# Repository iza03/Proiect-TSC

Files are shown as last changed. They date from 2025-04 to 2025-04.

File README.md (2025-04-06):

# DeskAssistant v1.5 – README

## Diagrama bloc
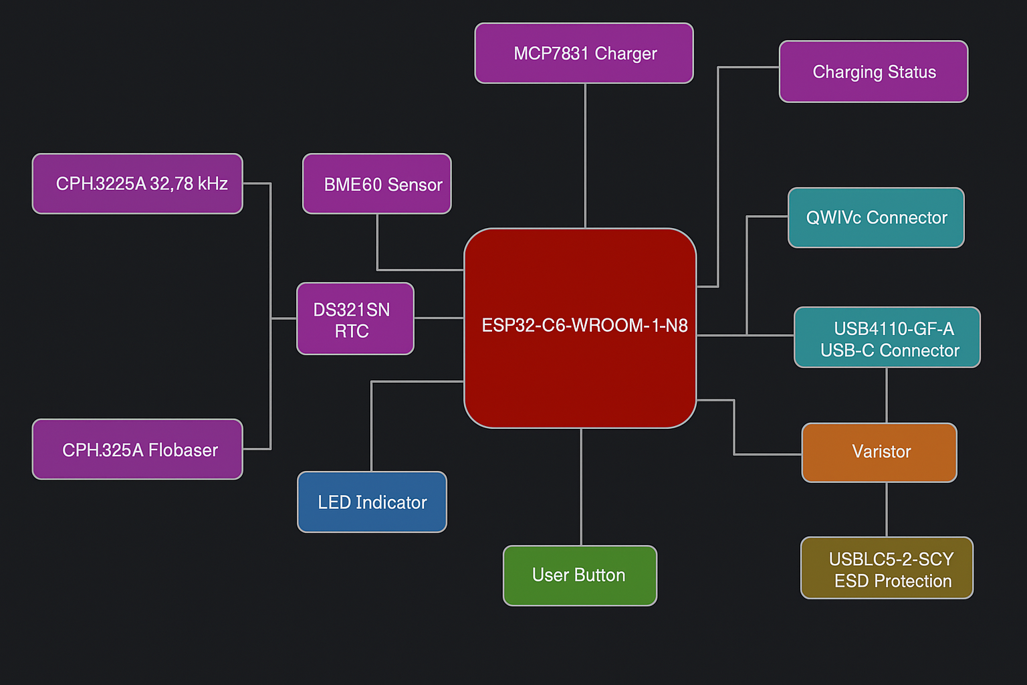
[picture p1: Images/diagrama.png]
Diagrama bloc


---

## Bill of Materials (BoM)

# Bill of Materials

| Componenta | Link |
|---|---|
| SAMACSYS_PARTS_USB4110-GF-A | [https://componentsearchengine.com/part-view/USB4110-GF-A/GCT%20(GLOBAL%20CONNECTOR%20TECHNOLOGY)](https://componentsearchengine.com/part-view/USB4110-GF-A/GCT%20(GLOBAL%20CONNECTOR%20TECHNOLOGY)) |
| SI1308EDL-T1-GE3 | [https://componentsearchengine.com/part-view/SI1308EDL-T1-GE3/Vishay](https://componentsearchengine.com/part-view/SI1308EDL-T1-GE3/Vishay) |
| SJ | [https://grabcad.com/library/solder-jumpers-1](https://grabcad.com/library/solder-jumpers-1) |
| USBLC6-2SC6Y | [https://www.snapeda.com/parts/USBLC6-2SC6Y/STMicroelectronics/view-part/?ref=eda](https://www.snapeda.com/parts/USBLC6-2SC6Y/STMicroelectronics/view-part/?ref=eda) |
| W25Q512JVEIQ | [https://www.snapeda.com/parts/W25Q512JVEIQ/Winbond+Electronics/view-part/?ref=eda](https://www.snapeda.com/parts/W25Q512JVEIQ/Winbond+Electronics/view-part/?ref=eda) |
| ESP32_WROVER_EAGLE-LTSPICE_RR0402 | [https://www.snapeda.com/parts/RC0402FR-07226RL/Yageo/view-part/](https://www.snapeda.com/parts/RC0402FR-07226RL/Yageo/view-part/) |
| ESP32C6_VARISTORCN1812 | [https://www.mouser.co.uk/ProductDetail/EPCOS-TDK/B72520T0350K062?qs=dEfas%2FXlABIszF52uu7vrg%3D%3D](https://www.mouser.co.uk/ProductDetail/EPCOS-TDK/B72520T0350K062?qs=dEfas%2FXlABIszF52uu7vrg%3D%3D) |
| FH34SRJ-24S-0.5SH_99_ | [https://componentsearchengine.com/part-view/XC6220A331MR-G/Torex](https://componentsearchengine.com/part-view/XC6220A331MR-G/Torex) |
| MAX17048G+T10 | [https://www.snapeda.com/parts/MAX17048G+T10/Analog+Devices/view-part/?ref=eda](https://www.snapeda.com/parts/MAX17048G+T10/Analog+Devices/view-part/?ref=eda) |
| MBR0530 | [https://ro.mouser.com/ProductDetail/KYOCERA-AVX/SD0805S020S1R0?qs=jCA%252BPfw4LHbpkAoSnwrdjw%3D%3D](https://ro.mouser.com/ProductDetail/KYOCERA-AVX/SD0805S020S1R0?qs=jCA%252BPfw4LHbpkAoSnwrdjw%3D%3D) |
| PGB1010603MR | [https://www.snapeda.com/parts/PGB1010603MR/Littelfuse/view-part/?ref=eda](https://www.snapeda.com/parts/PGB1010603MR/Littelfuse/view-part/?ref=eda) |
| RCL_CPOL-EUCT3528 | [https://ro.mouser.com/ProductDetail/Vishay-Sprague/TR3B106K025C1300?qs=jCGqFXxTmLdffnuDkXzk1g%3D%3D](https://ro.mouser.com/ProductDetail/Vishay-Sprague/TR3B106K025C1300?qs=jCGqFXxTmLdffnuDkXzk1g%3D%3D) |
| 112A-TAAR-R03_ATTEND | [https://store.comet.bg/en/Catalogue/Product/43497/](https://store.comet.bg/en/Catalogue/Product/43497/) |
| 744043680IND_4828-WE-TPC_WRE | [https://www.digikey.sg/en/models/1638515](https://www.digikey.sg/en/models/1638515) |
| BD5229G-TR | [https://componentsearchengine.com/part-view/BD5229G-TR/ROHM%20Semiconductor](https://componentsearchengine.com/part-view/BD5229G-TR/ROHM%20Semiconductor) |
| DS3231SN | [https://www.snapeda.com/parts/DS3231SN%23/Analog+Devices/view-part/?ref=eda](https://www.snapeda.com/parts/DS3231SN%23/Analog+Devices/view-part/?ref=eda) |
| ESP32-C6-WROOM-1-N8 | [https://www.snapeda.com/parts/ESP32-C6-WROOM-1-N8/Espressif+Systems/view-part/?ref=eda](https://www.snapeda.com/parts/ESP32-C6-WROOM-1-N8/Espressif+Systems/view-part/?ref=eda) |
| MCP73831 | [https://www.digikey.com/en/models/1874108](https://www.digikey.com/en/models/1874108) |
| XC6220A331MR-G | [https://componentsearchengine.com/part-view/XC6220A331MR-G/Torex](https://componentsearchengine.com/part-view/XC6220A331MR-G/Torex) |
| QWIIC_CONNECTORJS-1MM | [https://www.snapeda.com/parts/PRT-14417/SparkFun/view-part/](https://www.snapeda.com/parts/PRT-14417/SparkFun/view-part/) |
| BUTTON_CUSYOMV1 | [https://industry.panasonic.com/global/en/downloads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](https://industry.panasonic.com/global/en/downloads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) |
| ESP32_WROVER_EAGLE-LTSPICE_CC0402 | [https://componentsearchengine.com/part-view/CC0402MRX5R5BB106/YAGEO](https://componentsearchengine.com/part-view/CC0402MRX5R5BB106/YAGEO) |
| CPH3225A | [https://www.snapeda.com/parts/CPH3225A/Seiko+Instruments/view-part/?ref=eda](https://www.snapeda.com/parts/CPH3225A/Seiko+Instruments/view-part/?ref=eda) |
| ADAFRUIT_LEDCHIP-LED0603 | [https://www.snapeda.com/parts/KP-1608SURCK/Kingbright/view-part/?ref=search&t=LED%200603](https://www.snapeda.com/parts/KP-1608SURCK/Kingbright/view-part/?ref=search&t=LED%200603) |
| ESP32_WROVER_BME680_BME680 | [https://www.snapeda.com/parts/BME680/Bosch/view-part/?welcome=home](https://www.snapeda.com/parts/BME680/Bosch/view-part/?welcome=home) |
| ESP32_WROVER_SPARKFUN-DISCRETESEMI_MOSFET_PCH-DMG2305UX-7 | [https://componentsearchengine.com/part-view/DMG2305UX-7/Diodes%20Incorporated](https://componentsearchengine.com/part-view/DMG2305UX-7/Diodes%20Incorporated) |

---

## Funcționalități hardware

### 1. Microcontroller – ESP32-C6-WROOM-1-N8
- **Wireless:** WiFi 6, BLE 5.0, Zigbee, Thread
- **Interfețe:** UART, I²C, SPI, USB, ADC, PWM
- **Rol:** Unitate centrală de control, achiziție date, comunicare cu periferice și backend.

### 2. Senzori
- **BME688**: măsoară temperatură, umiditate, presiune și compuși organici volatili (VOC)
  - **Interfață**: I²C
- **DS3231SN**: RTC (Real Time Clock)
  - **Interfață**: I²C
- **MAX17048**: fuel gauge pentru baterie
  - **Interfață**: I²C

### 3. Memorie externă
- **W25Q512JVEIQ**
  - **Tip**: NOR Flash, 512Mbit
  - **Interfață**: SPI

### 4. Managementul energiei
- **MCP73831**: încărcător Li-Ion
- **MAX17048**: monitorizare baterie
- **BD5229G-TR**: LDO pentru 2.9V stabil
- **Diodă Schottky, MOSFET, varistor**: protecție la supratensiuni și polarizare inversă

### 5. Conectivitate și I/O
- **USB4110-GF-A**: conector USB-C pentru alimentare/comunicare
- **QWIIC connector**: I²C modular pentru senzori plug-and-play
- **LED status** și **buton fizic** (boot/reset sau input utilizator)

---

## Conexiuni GPIO la ESP32-C6

| Componentă | Interfață | GPIO ESP32-C6 | Funcție |
|---|---|---|---|
| BME688 / DS3231 / MAX17048 | I²C | GPIO8 (SDA), GPIO9 (SCL) | Magistrală partajată |
| W25Q512JVEIQ | SPI | GPIO4 (MOSI), GPIO5 (MISO), GPIO6 (CLK), GPIO7 (CS) | Comunicare cu flash extern |
| LED status | GPIO | GPIO3 | Indicator status / PWM |
| Buton | GPIO + Pull-up | GPIO0 | Reset / boot / input utilizator |
| MCP73831 – STAT | GPIO | GPIO10 | Monitorizare stare încărcare |
| MAX17048 – ALERT | GPIO (Interrupt) | GPIO1 | Notificare SoC critic |
| USB-C – D+ / D- | USB | GPIO18 (D+), GPIO19 (D-) | Comunicare USB nativă |

---

## Estimare consum energetic

| Componentă | Consum tipic |
|---|---|
| ESP32-C6 | ~130 mA (activ) |
| BME688 | ~3.1 µA |
| DS3231 | ~200 nA |
| MAX17048 | ~23 µA |
| MCP73831 | până la 500 mA (în încărcare) |
| LED-uri | 2–10 mA |

**Consum total în mod activ:** aprox. **150–180 mA**

### Randări PCB și design fizic

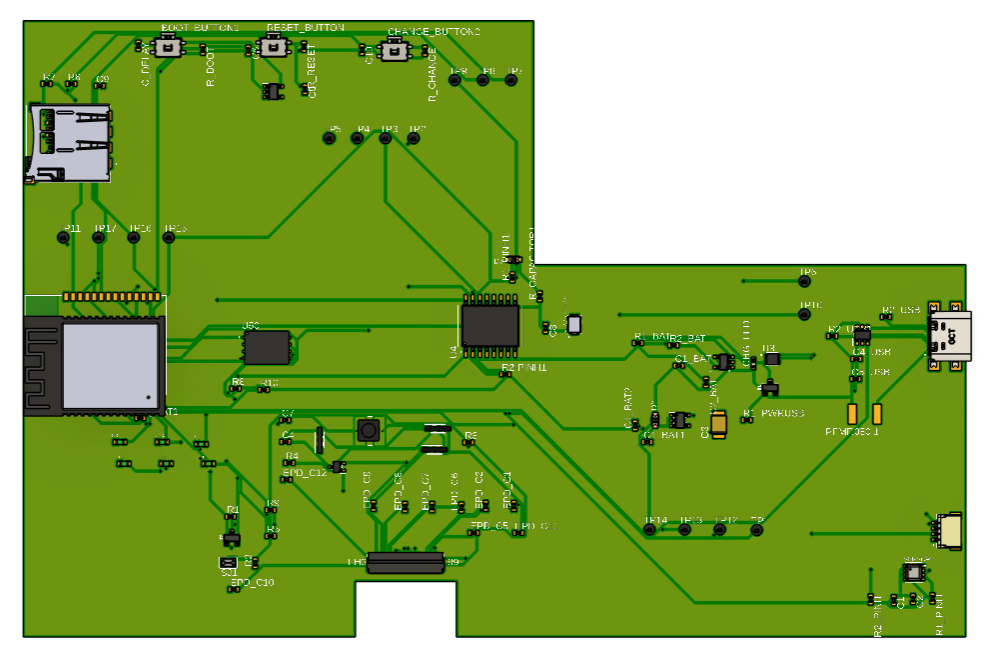
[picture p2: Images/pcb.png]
Randare PCB
  
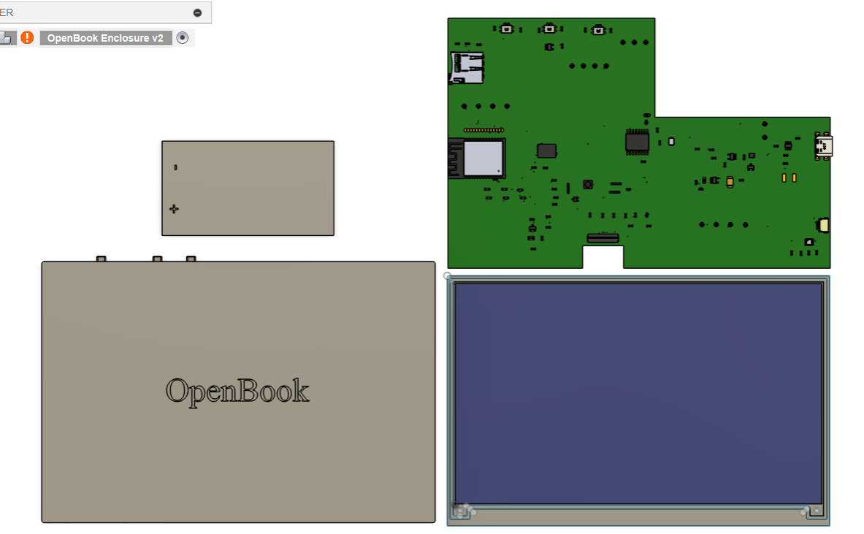
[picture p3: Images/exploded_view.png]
Vedere explodată
  
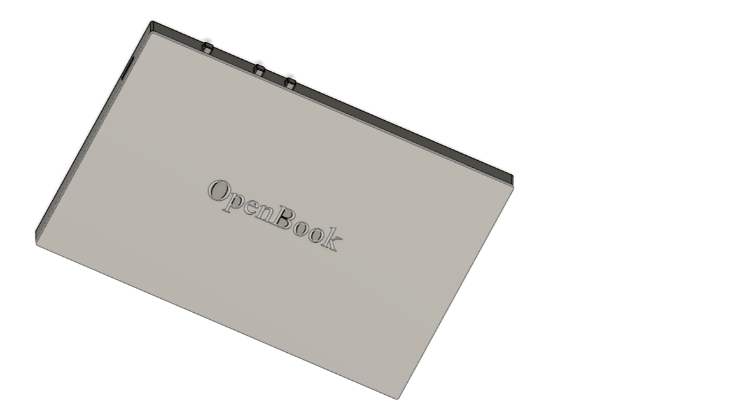
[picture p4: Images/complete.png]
Ansamblu complet


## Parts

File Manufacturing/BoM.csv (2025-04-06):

Qty | Value | Device | Package | Parts | Description | ARROW_PART_NUMBER | ARROW_PRICE-STOCK | AVAILABILITY | CENTROID_NOT_SPECIFIED | CHECK_PRICES | COPYRIGHT | DATASHEET | DESCRIPTION | DIGIKEY_DESCRIPTION | DIGIKEY_PART_NUMBER | HEIGHT | LEAD_FREE | MANUFACTURER_NAME | MANUFACTURER_PART_NUMBER | MF | MFR_NAME | MOUSER_PART_NUMBER | MOUSER_PRICE-STOCK | MOUSER_TESTING_PART_NUMBER | MOUSER_TESTING_PRICE-STOCK | MP | MPN | PACKAGE | POPULARITY | PREFIX | PRICE | PROD_ID | PURCHASE-URL | ROHS | SNAPEDA_LINK | SPICEMODEL | SPICEPREFIX | TEMPERATURE_RANGE_HIGH | TEMPERATURE_RANGE_LOW | TP_SIGNAL_NAME | VALUE
1 |  | ADAFRUIT_LEDCHIP-LED0603 | ADAFRUIT_CHIP-LED0603 | CHG_LED | LED
1 |  | SJ | SJ | SJ1 | SMD solder JUMPER |  |  |  |  |  |  |  |  |  |  |  |  |  |  |  |  |  |  |  |  |  |  |  | 3
1 | 0.1uF/50V | EAGLE-LTSPICE_CC0402 | EAGLE-LTSPICE_C0402 | EPD_C5 | CAPACITOR, European symbol |  |  |  |  |  |  |  |  |  |  |  |  |  |  |  |  |  |  |  |  |  |  |  |  |  |  |  |  |  |  | NONE | C
1 | 0.47 | ESP32_WROVER_EAGLE-LTSPICE_RR0402 | ESP32_WROVER_EAGLE-LTSPICE_R0402 | R3 | RESISTOR, European symbol |  |  |  |  |  |  |  |  |  |  |  |  |  |  |  |  |  |  |  |  |  |  |  |  |  |  |  |  |  |  | NONE | R
1 | 100k | ESP32_WROVER_EAGLE-LTSPICE_RR0402 | ESP32_WROVER_EAGLE-LTSPICE_R0402 | R1_PWRUSB | RESISTOR, European symbol |  |  |  |  |  |  |  |  |  |  |  |  |  |  |  |  |  |  |  |  |  |  |  |  |  |  |  |  |  |  | NONE | R
7 | 100nF | EAGLE-LTSPICE_CC0402 | EAGLE-LTSPICE_C0402 | C4_USB, C5_USB, C6, C8, C9, C10, C_DELAY | CAPACITOR, European symbol |  |  |  |  |  |  |  |  |  |  |  |  |  |  |  |  |  |  |  |  |  |  |  |  |  |  |  |  |  |  | NONE | C
2 | 100uF | EAGLE-LTSPICE_CC0402 | EAGLE-LTSPICE_C0402 | C1, C2 | CAPACITOR, European symbol |  |  |  |  |  |  |  |  |  |  |  |  |  |  |  |  |  |  |  |  |  |  |  |  |  |  |  |  |  |  | NONE | C
1 | 100uF TANT | RCL_CPOL-EUCT3528 | RCL_CT3528 | C3 | POLARIZED CAPACITOR, European symbol |  |  |  |  |  |  |  |  |  |  |  |  |  |  |  |  |  |  |  |  |  |  |  | 0 |  |  |  |  |  |  |  | C
11 | 10K | ESP32_WROVER_EAGLE-LTSPICE_RR0402 | ESP32_WROVER_EAGLE-LTSPICE_R0402 | R1, R4, R5, R6, R7, R8, R9, R10, R_BOOT, R_CHANGE, R_RESET | RESISTOR, European symbol |  |  |  |  |  |  |  |  |  |  |  |  |  |  |  |  |  |  |  |  |  |  |  |  |  |  |  |  |  |  | NONE | R
4 | 10k | ESP32_WROVER_EAGLE-LTSPICE_RR0402 | ESP32_WROVER_EAGLE-LTSPICE_R0402 | R1_PINH, R1_PINH1, R2-PINH1, R2_PINH | RESISTOR, European symbol |  |  |  |  |  |  |  |  |  |  |  |  |  |  |  |  |  |  |  |  |  |  |  |  |  |  |  |  |  |  | NONE | R
1 | 10uF | EAGLE-LTSPICE_CC0402 | EAGLE-LTSPICE_C0402 | C7 | CAPACITOR, European symbol |  |  |  |  |  |  |  |  |  |  |  |  |  |  |  |  |  |  |  |  |  |  |  |  |  |  |  |  |  |  | NONE | C
1 | 112A-TAAR-R03_ATTEND | 112A-TAAR-R03_ATTEND | 112ATAARR03ATTEND | J4 | Micro SD Card Socket, Push-Push Type, Top Mount, SMT, H=1.83mm, 10u |  |  |  |  |  |  |  | Micro SD Card Socket | Push-Push Type | Top Mount | SMT | H=1.83mm | 10u |  |  | 1.9mm |  | ATTEND | 112A-TAAR-R03 ATTEND
1 | 15 | ESP32_WROVER_EAGLE-LTSPICE_RR0402 | ESP32_WROVER_EAGLE-LTSPICE_R0402 | R_CAPACITOR1 | RESISTOR, European symbol |  |  |  |  |  |  |  |  |  |  |  |  |  |  |  |  |  |  |  |  |  |  |  |  |  |  |  |  |  |  | NONE | R
1 | 1uF | EAGLE-LTSPICE_CC0402 | EAGLE-LTSPICE_C0402 | C5 | CAPACITOR, European symbol |  |  |  |  |  |  |  |  |  |  |  |  |  |  |  |  |  |  |  |  |  |  |  |  |  |  |  |  |  |  | NONE | C
9 | 1uF/50V | EAGLE-LTSPICE_CC0402 | EAGLE-LTSPICE_C0402 | EPD_C1, EPD_C2, EPD_C6, EPD_C7, EPD_C8, EPD_C9, EPD_C10, EPD_C11, EPD_C12 | CAPACITOR, European symbol |  |  |  |  |  |  |  |  |  |  |  |  |  |  |  |  |  |  |  |  |  |  |  |  |  |  |  |  |  |  | NONE | C
1 | 2.2 | ESP32_WROVER_EAGLE-LTSPICE_RR0402 | ESP32_WROVER_EAGLE-LTSPICE_R0402 | R2 | RESISTOR, European symbol |  |  |  |  |  |  |  |  |  |  |  |  |  |  |  |  |  |  |  |  |  |  |  |  |  |  |  |  |  |  | NONE | R
1 | 200 | ESP32_WROVER_EAGLE-LTSPICE_RR0402 | ESP32_WROVER_EAGLE-LTSPICE_R0402 | R1_BAT | RESISTOR, European symbol |  |  |  |  |  |  |  |  |  |  |  |  |  |  |  |  |  |  |  |  |  |  |  |  |  |  |  |  |  |  | NONE | R
2 | 20V/4.2A/52mO/1.4W | ESP32_WROVER_SPARKFUN-DISCRETESEMI_MOSFET_PCH-DMG2305UX-7 | ESP32_WROVER_SPARKFUN-DISCRETESEMI_SOT23-3 | Q1, Q2 | P-channel MOSFETs |  |  |  |  |  |  |  |  |  |  |  |  |  |  |  |  |  |  |  |  |  |  |  |  |  |  | TRAN-14388 |  |  |  |  |  |  |  |  | 20V/4.2A/52mO/1.4W
1 | 25V | MBR0530 | SOD3716X135N | D5 | ON SEMICONDUCTOR - MBR0530 - DIODE, SCHOTTKY, 0.5A, 30V, SOD-123 |  |  | In Stock |  | https://www.snapeda.com/parts/MBR0530/Onsemi/view-part/?ref=eda |  |  | Diode Schottky 30 V 500mA Surface Mount SOD-123 |  |  |  |  |  |  | ON Semiconductor |  |  |  |  |  | MBR0530 |  | SOD-123-2 ON Semiconductor |  |  | None |  | https://www.snapeda.com/api/url_track_click_mouser/?unipart_id=179458&manufacturer=ON Semiconductor&part_name=MBR0530&search_term=None |  | https://www.snapeda.com/parts/MBR0530/Onsemi/view-part/?ref=snap
2 | 2K | ESP32_WROVER_EAGLE-LTSPICE_RR0402 | ESP32_WROVER_EAGLE-LTSPICE_R0402 | R2_BAT, R2_BAT1 | RESISTOR, European symbol |  |  |  |  |  |  |  |  |  |  |  |  |  |  |  |  |  |  |  |  |  |  |  |  |  |  |  |  |  |  | NONE | R
5 | 4.7uF | EAGLE-LTSPICE_CC0402 | EAGLE-LTSPICE_C0402 | C1_BAT, C1_BAT1, C1_BAT2, C2_BAT, C4 | CAPACITOR, European symbol |  |  |  |  |  |  |  |  |  |  |  |  |  |  |  |  |  |  |  |  |  |  |  |  |  |  |  |  |  |  | NONE | C
2 | 5k1 | ESP32_WROVER_EAGLE-LTSPICE_RR0402 | ESP32_WROVER_EAGLE-LTSPICE_R0402 | R2_USB, R2_USB1 | RESISTOR, European symbol |  |  |  |  |  |  |  |  |  |  |  |  |  |  |  |  |  |  |  |  |  |  |  |  |  |  |  |  |  |  | NONE | R
1 | 68uH | 744043680IND_4828-WE-TPC_WRE | IND_4828-WE-TPC_WRE | L1 |  |  |  |  |  |  | Copyright (C) 2024 Ultra Librarian. All rights reserved. |  |  |  |  |  |  |  | 744043680 |  | Wurth Electronics
1 | BD5229G-TR | BD5229G-TR | SOT95P280X125-5N | IC1 | Voltage Detector with Adjustable Delay Time: CMOS processes are utilized to develop high precision, low current consumption CMOS reset ICs that allow arbitrary setting of the delay time. The extensive lineup includes both Nch Open Drain and CMOS output types in a wide range of detection voltages (from 2.3V to 6.0V, in 0.1V steps), enabling selection of the ideal solution based on customer requirements. In addition, the entire series is of course both lead-free and RoHS-compliant. |  |  |  |  |  |  |  | Voltage Detector with Adjustable Delay Time: CMOS processes are utilized to develop high precision | low current consumption CMOS reset ICs that allow arbitrary setting of the delay time. The extensive lineup includes both Nch Open Drain and CMOS output types in a wide range of detection voltages (from 2.3V to 6.0V | in 0.1V steps) | enabling selection of the ideal solution based on customer requirements. In addition | the entire series is of course both lead-free and RoHS-compliant. |  |  | 1.25mm |  | ROHM Semiconductor | BD5229G-TR |  |  | 755-BD5229G-TR | https://www.mouser.co.uk/ProductDetail/ROHM-Semiconductor/BD5229G-TR?qs=4kLU8WoGk0vvnhrrYwdszw%3D%3D
2 | BUTTON_CUSYOMV1 | BUTTON_CUSYOMV1 | MYBUTTON | BOOT_BUTTON1, CHANGE_BUTTON2
1 | BUTTON_CUSYOMV1 | BUTTON_CUSYOMV1 | MYBUTTON | RESET_BUTTON |  |  |  |  |  |  |  |  |  |  |  |  |  |  |  |  |  |  |  |  |  |  |  |  |  |  |  |  |  |  |  |  | K
1 | CPH3225A | CPH3225A | CAPCP3225X100N | C10_SUPERCAP | Cap 0.011F 3.3V 1210 Flat Check availability |  |  | Not in stock |  | https://www.snapeda.com/parts/CPH3225A/Seiko+Instruments/view-part/?ref=eda |  |  | 11 mF (EDLC) Supercapacitor 3.3 V 1210 (3225 Metric) - - |  |  |  |  |  |  | Seiko Instruments |  |  |  |  |  | CPH3225A |  | 1210 Seiko |  |  | None |  | https://www.snapeda.com/api/url_track_click_mouser/?unipart_id=562593&manufacturer=Seiko Instruments&part_name=CPH3225A&search_term=None |  | https://www.snapeda.com/parts/CPH3225A/Seiko+Instruments/view-part/?ref=snap
1 | DS3231SN# | DS3231SN# | SOIC127P1032X265-16N | U4 | Real Time Clock Serial 16-Pin SOIC W T/R Check availability |  |  | In Stock |  | https://www.snapeda.com/parts/DS3231SN%23/Analog+Devices/view-part/?ref=eda |  |  | Extremely Accurate I²C-Integrated RTC/TCXO/Crystal |  |  |  |  |  |  | Analog Devices |  |  |  |  |  | DS3231SN# |  | SOIC-16 Maxim |  |  | None |  | https://www.snapeda.com/api/url_track_click_mouser/?unipart_id=99048&manufacturer=Analog Devices&part_name=DS3231SN#&search_term=None |  | https://www.snapeda.com/parts/DS3231SN%23/Analog+Devices/view-part/?ref=snap
1 | ESP32-C6-WROOM-1-N8 | ESP32-C6-WROOM-1-N8 | XCVR_ESP32-C6-WROOM-1-N8 | U2 | Check availability |  |  | In Stock |  | https://www.snapeda.com/parts/ESP32-C6-WROOM-1-N8/Espressif+Systems/view-part/?ref=eda |  |  | Multiprotocol Modules ESP32-C6 module | Wi-Fi 6 in 2.4 GHz band | Bluetooth 5 | Zigbee 3.0 and Thread. ESP34-WROOM Compatible - ENGINEERING SAMPLE |  |  |  |  |  |  | Espressif Systems |  |  |  |  |  | ESP32-C6-WROOM-1-N8 |  | None |  |  | None |  |  |  | https://www.snapeda.com/parts/ESP32-C6-WROOM-1-N8/Espressif+Systems/view-part/?ref=snap
1 | ESP32C6_VARISTORCN1812 | ESP32C6_VARISTORCN1812 | ESP32C6_VARISTOR_CT/CN1812 | PFMF.050.1 | VARISTOR |  |  |  |  |  |  |  |  |  |  |  |  |  |  |  |  |  |  |  |  |  |  |  | 0
2 | ESP32_WROVER_AVX---SD0805S020S1R0_AVX_SD0805S020S1R0_0_0AVX_SD0805S020S1R0_0_0 | ESP32_WROVER_AVX---SD0805S020S1R0_AVX_SD0805S020S1R0_0_0AVX_SD0805S020S1R0_0_0 | ESP32_WROVER_AVX---SD0805S020S1R0_AVX_SD0805S020S1R0_0 | D2, D7 | Schottky Barrier Rectifier Diode |  |  |  | No |  |  | http://datasheets.avx.com/schottky.pdf |  | DIODE SCHOTTKY 20V 1A 0805 | 478-7800-1-ND |  | yes |  |  | AVX |  | 581-SD0805S020S1R0 |  |  |  |  |  | 0805 (2012 metric) |  | D |  |  |  | yes |  |  |  | +125°C | -55°C
1 | ESP32_WROVER_BME680_BME680 | ESP32_WROVER_BME680_BME680 | ESP32_WROVER_BME680_PSON80P300X300X100-8N | SENSOR2 | Integrated Environmental Unit |  |  | Unavailable |  |  |  |  | Integrated Environmental Unit |  |  |  |  |  |  | Bosch Sensortec |  |  |  |  |  | BME680 |  | LGA-8 Bosch Tools |  |  | None
1 | ESP32_WROVER_SPARKFUN-IC-POWER_MCP73831 | ESP32_WROVER_SPARKFUN-IC-POWER_MCP73831 | ESP32_WROVER_SPARKFUN-IC-POWER_SOT23-5 | U1 | MCP73831T Li-Ion, Li-Pol Controller |  |  |  |  |  |  |  |  |  |  |  |  |  |  |  |  |  |  |  |  |  |  |  |  |  |  | IC-09995
1 | FH34SRJ-24S-0.5SH_99_ | FH34SRJ-24S-0.5SH_99_ | FH34SRJ24S05SH99 | FH34SRJ-24S-0.5SH_99_ | (0.50mm) Surface Mount, Right Angle |  |  |  |  |  |  |  | 24 Position FFC | FPC Connector Contacts | (0.50mm) Surface Mount | Right Angle |  |  | 1.1mm |  | Hirose | FH34SRJ-24S-0.5SH(99) |  |  | 798-FH34SRJ24S05SH99 | https://www.mouser.co.uk/ProductDetail/Hirose-Connector/FH34SRJ-24S-0.5SH99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
1 | MAX17048G+T10 | MAX17048G+T10 | SON50P200X200X80-9N | U3 | Check availability |  |  | In Stock |  | https://www.snapeda.com/parts/MAX17048G+T10/Analog+Devices/view-part/?ref=eda |  |  | 3µA 1-Cell/2-Cell Fuel Gauge with ModelGauge |  |  |  |  |  |  | Analog Devices |  |  |  |  |  | MAX17048G+T10 |  | TDFN-8 Maxim |  |  | None |  | https://www.snapeda.com/api/url_track_click_mouser/?unipart_id=329239&manufacturer=Analog Devices&part_name=MAX17048G+T10&search_term=None |  | https://www.snapeda.com/parts/MAX17048G+T10/Analog+Devices/view-part/?ref=snap
2 | MBR0530 | MBR0530 | SOD3716X135N | D3, D4 | ON SEMICONDUCTOR - MBR0530 - DIODE, SCHOTTKY, 0.5A, 30V, SOD-123 |  |  | In Stock |  | https://www.snapeda.com/parts/MBR0530/Onsemi/view-part/?ref=eda |  |  | Diode Schottky 30 V 500mA Surface Mount SOD-123 |  |  |  |  |  |  | ON Semiconductor |  |  |  |  |  | MBR0530 |  | SOD-123-2 ON Semiconductor |  |  | None |  | https://www.snapeda.com/api/url_track_click_mouser/?unipart_id=179458&manufacturer=ON Semiconductor&part_name=MBR0530&search_term=None |  | https://www.snapeda.com/parts/MBR0530/Onsemi/view-part/?ref=snap
6 | PGB1010603MR | PGB1010603MR | DIOC1608X36N | D8, D9, D10, D11, D12, D700 | Check availability |  |  | In Stock |  | https://www.snapeda.com/parts/PGB1010603MR/Littelfuse/view-part/?ref=eda |  |  | 150V (Typ) Clamp - Ipp Tvs Diode Surface Mount 0603 (1608 Metric) |  |  |  |  |  |  | Littelfuse Inc. |  |  |  |  |  | PGB1010603MR |  | 0603 Littelfuse Inc. |  |  | None |  | https://www.snapeda.com/api/url_track_click_mouser/?unipart_id=5659453&manufacturer=Littelfuse Inc.&part_name=PGB1010603MR&search_term=None |  | https://www.snapeda.com/parts/PGB1010603MR/Littelfuse/view-part/?ref=snap
1 | QWIIC_RIGHT_ANGLE | QWIIC_CONNECTORJS-1MM | JST04_1MM_RA | J3 | SparkFun I2C Standard Qwiic Connector |  |  |  |  |  |  |  |  |  |  |  |  |  |  |  |  |  |  |  |  |  |  |  |  |  |  | CONN-13694 |  |  |  |  |  |  |  |  | QWIIC_RIGHT_ANGLE
1 | SAMACSYS_PARTS_USB4110-GF-A | SAMACSYS_PARTS_USB4110-GF-A | SAMACSYS_PARTS_USB4110GFA | J2 | CONN USB 2.0 TYPE-C R/A SMT |  |  |  |  |  |  |  | CONN USB 2.0 TYPE-C R/A SMT |  |  | 3.26mm |  | GCT (GLOBAL CONNECTOR TECHNOLOGY) | USB4110-GF-A |  |  | 640-USB4110-GF-A | https://www.mouser.co.uk/ProductDetail/GCT/USB4110-GF-A?qs=KUoIvG%2F9IlYiZvIXQjyJeA%3D%3D
1 | SI1308EDL-T1-GE3 | SI1308EDL-T1-GE3 | SOT65P210X110-3N | Q3 | MOSFET N-Ch 30V 1.5A TrenchFET SC70 Vishay Si1308EDL-T1-GE3 N-channel MOSFET Transistor, 1.5 A, 30 V, 3-Pin SC-70 |  |  | In Stock |  | https://www.snapeda.com/parts/SI1308EDL-T1-GE3/Vishay+Siliconix/view-part/?ref=eda |  |  | Si1308EDL-T1-GE3 N-channel MOSFET Transistor | 1.5 A | 30 V | 3-Pin SC-70 | Siliconix / Vishay SI1308EDL-T1-GE3 |  |  |  |  |  |  | Vishay Siliconix |  |  |  |  |  | SI1308EDL-T1-GE3 |  | SOT-323 Vishay Semiconductor |  |  | None |  | https://www.snapeda.com/api/url_track_click_mouser/?unipart_id=274603&manufacturer=Vishay Siliconix&part_name=SI1308EDL-T1-GE3&search_term=None |  | https://www.snapeda.com/parts/SI1308EDL-T1-GE3/Vishay+Siliconix/view-part/?ref=snap
17 | TPTP20R | TPTP20R | TP20R | TP1, TP2, TP3, TP4, TP5, TP6, TP7, TP8, TP9, TP10, TP11, TP12, TP13, TP14, TP15, TP16, TP17 | Test pad |  |  |  |  |  |  |  |  |  |  |  |  |  |  |  |  |  |  |  |  |  |  |  | 2
1 | USBLC6-2SC6Y | USBLC6-2SC6Y | SOT95P280X145-6N | D1 | Low Cap. ESD Protection Auto SOT-23-6 STMicroelectronics USBLC6-2SC6Y, Dual Uni-Directional TVS Diode Array, 6-Pin SOT-23 |  |  | In Stock |  | https://www.snapeda.com/parts/USBLC6-2SC6Y/STMicroelectronics/view-part/?ref=eda |  |  | 17V Clamp 5A (8/20µs) Ipp Tvs Diode Surface Mount SOT-23-6 |  |  |  |  |  |  | STMicroelectronics |  |  |  |  |  | USBLC6-2SC6Y |  | SOT-23-6 STMicroelectronics |  |  | None |  |  |  | https://www.snapeda.com/parts/USBLC6-2SC6Y/STMicroelectronics/view-part/?ref=snap
1 | W25Q512JVEIQ | W25Q512JVEIQ | SON127P600X800X80-9N | U50 | Check availability |  |  | In Stock |  | https://www.snapeda.com/parts/W25Q512JVEIQ/Winbond+Electronics/view-part/?ref=eda |  |  | FLASH - NOR Memory IC 512Mb (64M x 8) SPI - Quad I/O 133 MHz 8-WSON (8x6) |  |  |  |  |  |  | Winbond Electronics |  |  |  |  |  | W25Q512JVEIQ |  | Package |  |  | None |  |  |  | https://www.snapeda.com/parts/W25Q512JVEIQ/Winbond+Electronics/view-part/?ref=snap
1 | XC6220A331MR-G | XC6220A331MR-G | SOT95P280X120-5N | IC4 | LDO Voltage Regulators |  |  |  |  |  |  |  | LDO Voltage Regulators |  |  | 1.2mm |  | Torex | XC6220A331MR-G |  |  | 865-XC6220A331MR-G | https://www.mouser.co.uk/ProductDetail/Torex-Semiconductor/XC6220A331MR-G?qs=AsjdqWjXhJ8ZSWznL1J0gg%3D%3D

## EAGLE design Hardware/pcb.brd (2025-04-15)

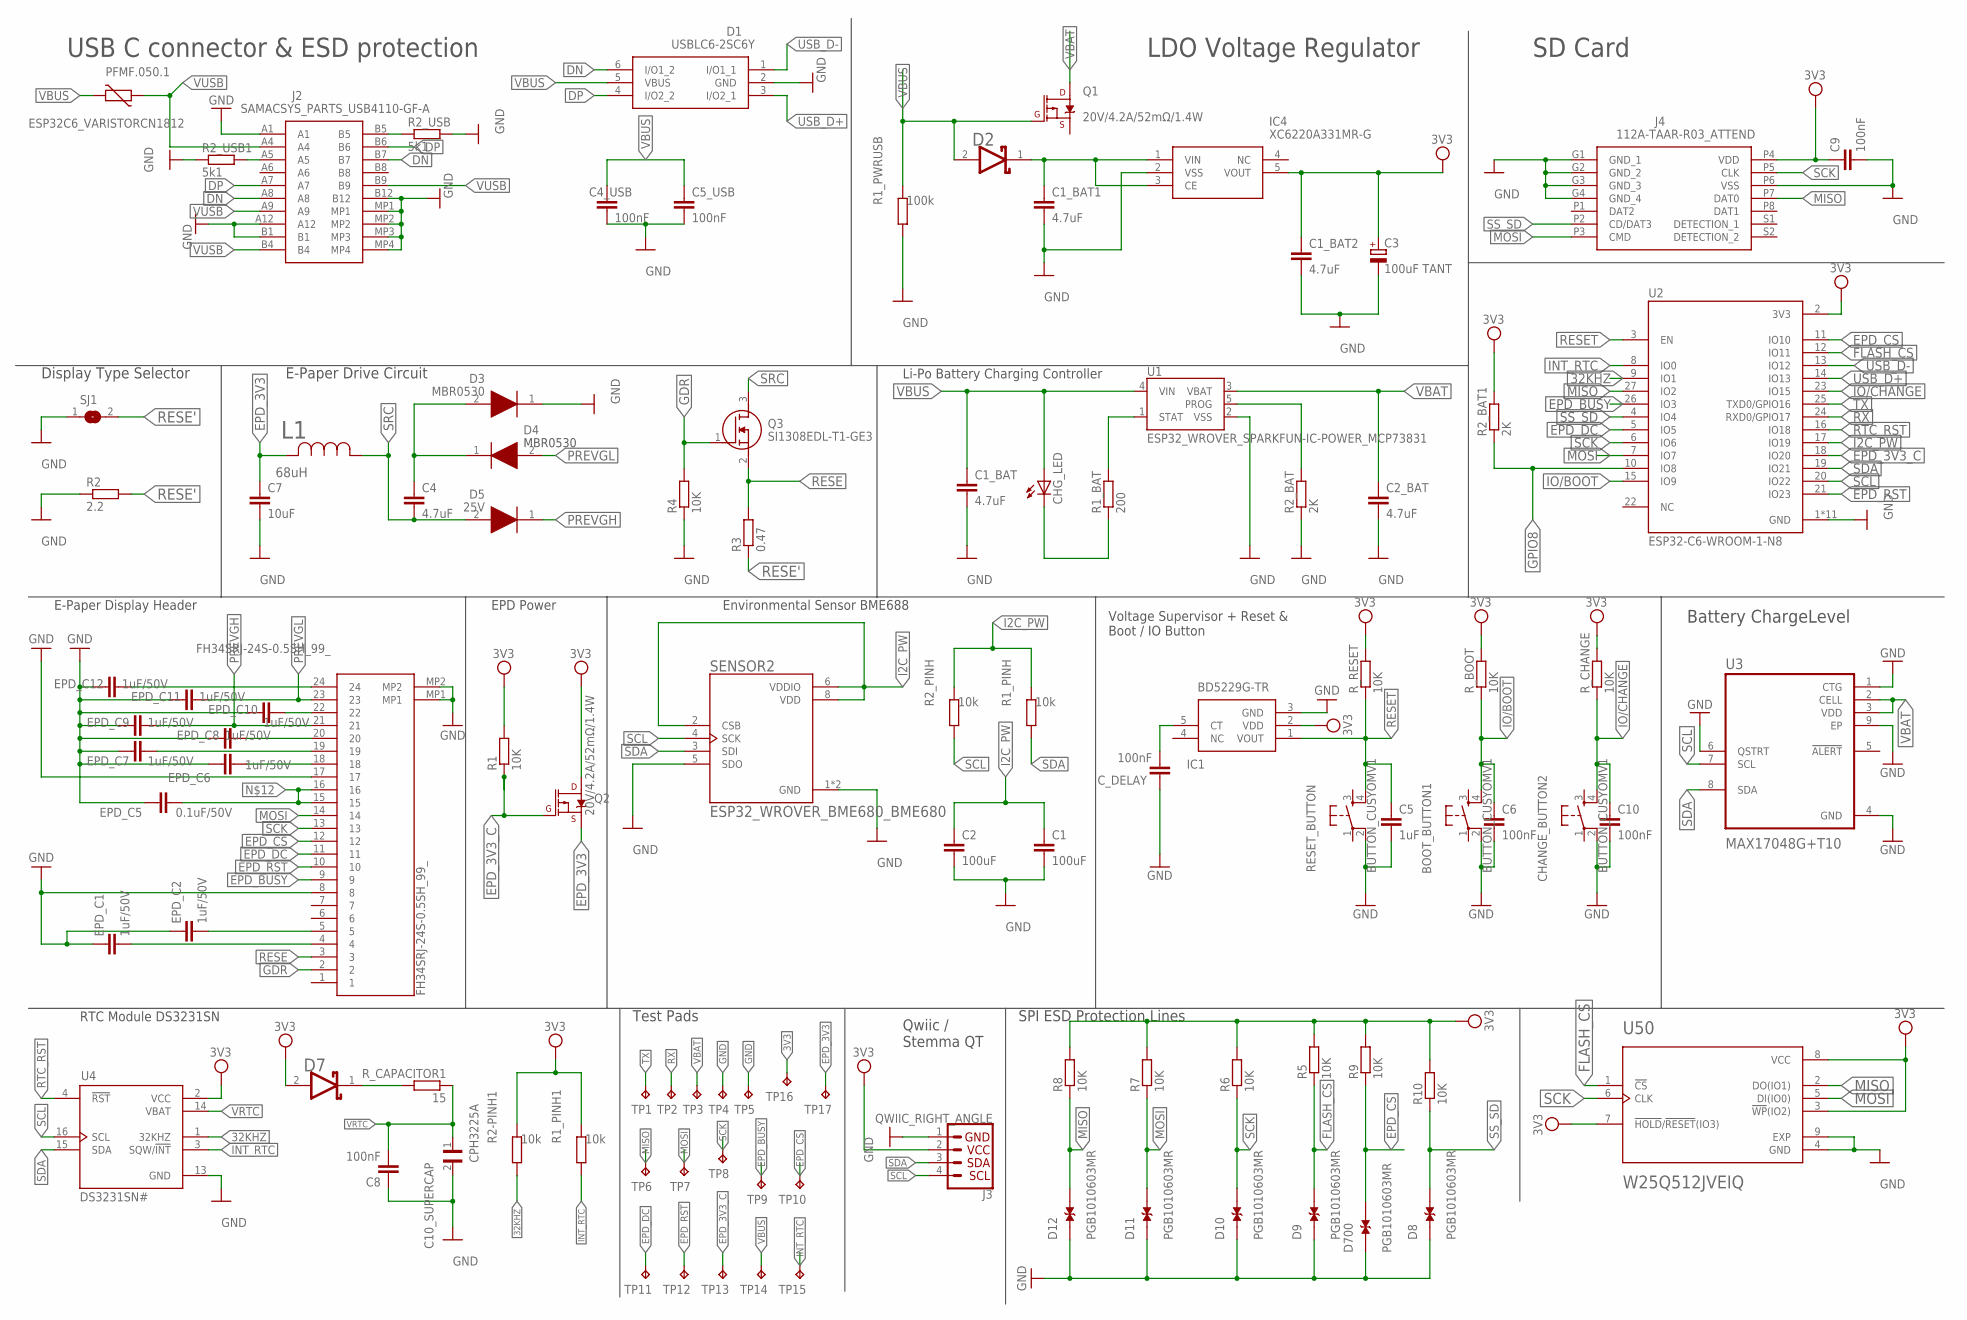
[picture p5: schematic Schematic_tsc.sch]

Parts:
BOOT_BUTTON1: BUTTON_CUSYOMV1; MYBUTTON
C1, C2: 100uF; EAGLE-LTSPICE_C0402
C1_BAT, C1_BAT1, C1_BAT2, C2_BAT, C4: 4.7uF; EAGLE-LTSPICE_C0402
C3: 100uF TANT; RCL_CT3528
C4_USB, C5_USB, C6, C8, C9, C10: 100nF; EAGLE-LTSPICE_C0402
C5: 1uF; EAGLE-LTSPICE_C0402
C7: 10uF; EAGLE-LTSPICE_C0402
C10_SUPERCAP: CPH3225A; CAPCP3225X100N
CHANGE_BUTTON2: BUTTON_CUSYOMV1; MYBUTTON
CHG_LED: ADAFRUIT_LEDCHIP-LED0603; ADAFRUIT_CHIP-LED0603
C_DELAY: 100nF; EAGLE-LTSPICE_C0402
D1: USBLC6-2SC6Y; SOT95P280X145-6N
D2, D7: ESP32_WROVER_AVX---SD0805S020S1R0_AVX_SD0805S020S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; ESP32_WROVER_AVX---SD0805S020S1R0_AVX_SD0805S020S1R0_0
D3, D4: MBR0530; SOD3716X135N
D5: 25V; SOD3716X135N
D8, D9, D10, D11, D12, D700: PGB1010603MR; DIOC1608X36N
EPD_C1, EPD_C2, EPD_C6, EPD_C7, EPD_C8, EPD_C9, EPD_C10, EPD_C11, EPD_C12: 1uF/50V; EAGLE-LTSPICE_C0402
EPD_C5: 0.1uF/50V; EAGLE-LTSPICE_C0402
FH34SRJ-24S-0.5SH_99_: FH34SRJ-24S-0.5SH_99_; FH34SRJ24S05SH99
IC1: BD5229G-TR; SOT95P280X125-5N
IC4: XC6220A331MR-G; SOT95P280X120-5N
J2: SAMACSYS_PARTS_USB4110-GF-A; SAMACSYS_PARTS_USB4110GFA
J3: QWIIC_RIGHT_ANGLE; JST04_1MM_RA
J4: 112A-TAAR-R03_ATTEND; 112ATAARR03ATTEND
L1: 68uH; IND_4828-WE-TPC_WRE
PFMF.050.1: ESP32C6_VARISTORCN1812; ESP32C6_VARISTOR_CT/CN1812
Q1, Q2: 20V/4.2A/52mΩ/1.4W; ESP32_WROVER_SPARKFUN-DISCRETESEMI_SOT23-3
Q3: SI1308EDL-T1-GE3; SOT65P210X110-3N
R1, R4, R5, R6, R7, R8, R9, R10: 10K; ESP32_WROVER_EAGLE-LTSPICE_R0402
R1_BAT: 200; ESP32_WROVER_EAGLE-LTSPICE_R0402
R1_PINH, R1_PINH1, R2-PINH1, R2_PINH: 10k; ESP32_WROVER_EAGLE-LTSPICE_R0402
R1_PWRUSB: 100k; ESP32_WROVER_EAGLE-LTSPICE_R0402
R2: 2.2; ESP32_WROVER_EAGLE-LTSPICE_R0402
R2_BAT, R2_BAT1: 2K; ESP32_WROVER_EAGLE-LTSPICE_R0402
R2_USB, R2_USB1: 5k1; ESP32_WROVER_EAGLE-LTSPICE_R0402
R3: 0.47; ESP32_WROVER_EAGLE-LTSPICE_R0402
RESET_BUTTON: BUTTON_CUSYOMV1; MYBUTTON
R_BOOT: 10K; ESP32_WROVER_EAGLE-LTSPICE_R0402
R_CAPACITOR1: 15; ESP32_WROVER_EAGLE-LTSPICE_R0402
R_CHANGE: 10K; ESP32_WROVER_EAGLE-LTSPICE_R0402
R_RESET: 10K; ESP32_WROVER_EAGLE-LTSPICE_R0402
SENSOR2: ESP32_WROVER_BME680_BME680; ESP32_WROVER_BME680_PSON80P300X300X100-8N
SJ1: SJ
TP1, TP2, TP3, TP4, TP5, TP6, TP7, TP8, TP9, TP10, TP11, TP12, TP13, TP14, TP15, TP16, TP17: TPTP20R; TP20R
U1: ESP32_WROVER_SPARKFUN-IC-POWER_MCP73831; ESP32_WROVER_SPARKFUN-IC-POWER_SOT23-5
U2: ESP32-C6-WROOM-1-N8; XCVR_ESP32-C6-WROOM-1-N8
U3: MAX17048G+T10; SON50P200X200X80-9N
U4: DS3231SN#; SOIC127P1032X265-16N
U50: W25Q512JVEIQ; SON127P600X800X80-9N

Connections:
3V3: C1_BAT2.1, C3.+, C9.1, D7.2 (ANODE), IC1.2 (VDD), IC4.5 (VOUT), J3.2, J4.P4 (VDD), Q2.3 (D), R1.2, R1_PINH1.2, R2-PINH1.2, R2_BAT1.2, R5.2, R6.2, R7.2, R8.2, R9.2, R10.2, R_BOOT.2, R_CHANGE.2, R_RESET.2, TP16.TP, U2.2 (3V3), U4.2 (VCC), U50.3 (!WP!(IO2)), U50.7 (!HOLD!/!RESET!(IO3)), U50.8 (VCC)
32KHZ: R2-PINH1.1, U2.9 (IO1), U4.1 (32KHZ)
DN: D1.6 (I/O1_2), J2.A8, J2.B7
DP: D1.4 (I/O2_2), J2.A7, J2.B6
EPD_3V3: C7.1, L1.2, Q2.2 (S), TP17.TP
EPD_3V3_C: Q2.1 (G), R1.1, TP13.TP, U2.18 (IO20)
EPD_BUSY: FH34SRJ-24S-0.5SH_99_.9, TP9.TP, U2.26 (IO3)
EPD_CS: D700.2, FH34SRJ-24S-0.5SH_99_.12, R9.1, TP10.TP, U2.11 (IO10)
EPD_DC: FH34SRJ-24S-0.5SH_99_.11, TP11.TP, U2.5 (IO5)
EPD_RST: FH34SRJ-24S-0.5SH_99_.10, TP12.TP, U2.21 (IO23)
FLASH_CS: D9.2, R5.1, U2.12 (IO11), U50.1 (!CS)
GDR: FH34SRJ-24S-0.5SH_99_.2, Q3.1 (G), R4.2
GND: BOOT_BUTTON1.2, C1.2, C1_BAT.2, C1_BAT1.2, C1_BAT2.2, C2.2, C2_BAT.2, C3.-, C4_USB.2, C5.2, C5_USB.2, C6.2, C7.2, C8.1, C9.2, C10.2, C10_SUPERCAP.2, CHANGE_BUTTON2.2, C_DELAY.1, D1.2 (GND), D3.1 (K), D8.1, D9.1, D10.1, D11.1, D12.1, D700.1, EPD_C1.1, EPD_C2.1, EPD_C5.1, EPD_C6.1, EPD_C7.1, EPD_C8.1, EPD_C9.1, EPD_C10.1, EPD_C11.1, EPD_C12.1, FH34SRJ-24S-0.5SH_99_.8, FH34SRJ-24S-0.5SH_99_.17, FH34SRJ-24S-0.5SH_99_.MP1, FH34SRJ-24S-0.5SH_99_.MP2, IC1.3 (GND), IC4.2 (VSS), J2.A1, J2.A12, J2.B1, J2.B12, J2.MP1, J2.MP2, J2.MP3, J2.MP4, J3.1, J4.G1 (GND_1), J4.G2 (GND_2), J4.G3 (GND_3), J4.G4 (GND_4), J4.P6 (VSS), R1_PWRUSB.1, R2.1, R2_BAT.1, R2_USB.2, R2_USB1.1, R4.1, RESET_BUTTON.2, SENSOR2.1 (GND), SENSOR2.5 (SDO), SENSOR2.7 (GND), SJ1.1, TP4.TP, TP5.TP, U1.2 (VSS), U2.1 (GND), U2.28 (GND), U2.29_1 (GND), U2.29_2 (GND), U2.29_3 (GND), U2.29_4 (GND), U2.29_5 (GND), U2.29_6 (GND), U2.29_7 (GND), U2.29_8 (GND), U2.29_9 (GND), U3.1 (CTG), U3.4 (GND), U3.6 (QSTRT), U3.9 (EP), U4.13 (GND), U50.4 (GND), U50.9 (EXP)
GPIO8: R2_BAT1.1, U2.10 (IO8)
I2C_PW: C1.1, C2.1, R1_PINH.2, R2_PINH.2, SENSOR2.2 (CSB), SENSOR2.6 (VDDIO), SENSOR2.8 (VDD), U2.17 (IO19)
INT_RTC: R1_PINH1.1, TP15.TP, U2.8 (IO0), U4.3 (SQW/!INT)
IO/BOOT: BOOT_BUTTON1.4, C6.1, R_BOOT.1, U2.15 (IO9)
IO/CHANGE: C10.1, CHANGE_BUTTON2.4, R_CHANGE.1, U2.23 (IO15)
MISO: D12.2, J4.P7 (DAT0), R8.1, TP6.TP, U2.27 (IO2), U50.2 (DO(IO1))
MOSI: D11.2, FH34SRJ-24S-0.5SH_99_.14, J4.P3 (CMD), R7.1, TP7.TP, U2.7 (IO7), U50.5 (DI(IO0))
unnamed: J2.A5, R2_USB1.2
unnamed: J2.B5, R2_USB.1
unnamed: C1_BAT1.1, D2.1 (CATHODE), IC4.1 (VIN), IC4.3 (CE)
unnamed: EPD_C12.2, FH34SRJ-24S-0.5SH_99_.24
unnamed: C4.1, D3.2 (A), D4.1 (K)
unnamed: R1_BAT.2, U1.1 (STAT)
unnamed: CHG_LED.C, R1_BAT.1
unnamed: R2_BAT.2, U1.5 (PROG)
unnamed: EPD_C10.2, FH34SRJ-24S-0.5SH_99_.22
unnamed: EPD_C5.2, FH34SRJ-24S-0.5SH_99_.15, FH34SRJ-24S-0.5SH_99_.16
unnamed: EPD_C7.2, FH34SRJ-24S-0.5SH_99_.19
unnamed: EPD_C6.2, FH34SRJ-24S-0.5SH_99_.18
unnamed: EPD_C2.2, FH34SRJ-24S-0.5SH_99_.5
unnamed: EPD_C1.2, FH34SRJ-24S-0.5SH_99_.4
unnamed: C_DELAY.2, IC1.5 (CT)
unnamed: D7.1 (CATHODE), R_CAPACITOR1.2
unnamed: EPD_C8.2, FH34SRJ-24S-0.5SH_99_.20
PREVGH: D5.1 (K), EPD_C9.2, FH34SRJ-24S-0.5SH_99_.21
PREVGL: D4.2 (A), EPD_C11.2, FH34SRJ-24S-0.5SH_99_.23
RESE: FH34SRJ-24S-0.5SH_99_.3, Q3.2 (S), R3.2
RESE': R2.2, R3.1, SJ1.2
RESET: C5.1, IC1.1 (VOUT), RESET_BUTTON.4, R_RESET.1, U2.3 (EN)
RTC_RST: U2.16 (IO18), U4.4 (!RST)
RX: TP2.TP, U2.24 (RXD0/GPIO17)
SCK: D10.2, FH34SRJ-24S-0.5SH_99_.13, J4.P5 (CLK), R6.1, TP8.TP, U2.6 (IO6), U50.6 (CLK)
SCL: J3.4, R2_PINH.1, SENSOR2.4 (SCK), U2.20 (IO22), U3.7 (SCL), U4.16 (SCL)
SDA: J3.3, R1_PINH.1, SENSOR2.3 (SDI), U2.19 (IO21), U3.8 (SDA), U4.15 (SDA)
SRC: C4.2, D5.2 (A), L1.1, Q3.3 (D)
SS_SD: D8.2, J4.P2 (CD/DAT3), R10.1, U2.4 (IO4)
TX: TP1.TP, U2.25 (TXD0/GPIO16)
USB_D+: D1.3 (I/O2_1), U2.14 (IO13)
USB_D-: D1.1 (I/O1_1), U2.13 (IO12)
VBAT: C2_BAT.1, Q1.3 (D), TP3.TP, U1.3 (VBAT), U3.2 (CELL), U3.3 (VDD)
VBUS: C1_BAT.1, C4_USB.1, C5_USB.1, CHG_LED.A, D1.5 (VBUS), D2.2 (ANODE), PFMF.050.1.2, Q1.1 (G), R1_PWRUSB.2, TP14.TP, U1.4 (VIN)
VRTC: C8.2, C10_SUPERCAP.1, R_CAPACITOR1.1, U4.14 (VBAT)
VUSB: J2.A4, J2.A9, J2.B4, J2.B9, PFMF.050.1.1

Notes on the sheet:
SD Card
LDO Voltage Regulator
USB C connector & ESD protection
Display Type Selector
E-Paper Drive Circuit
Li-Po Battery Charging Controller
E-Paper Display Header
EPD Power
Environmental Sensor BME688
Voltage Supervisor + Reset & Boot / IO Button
RTC Module DS3231SN
Test Pads
Qwiic / Stemma QT
SPI ESD Protection Lines
Battery ChargeLevel

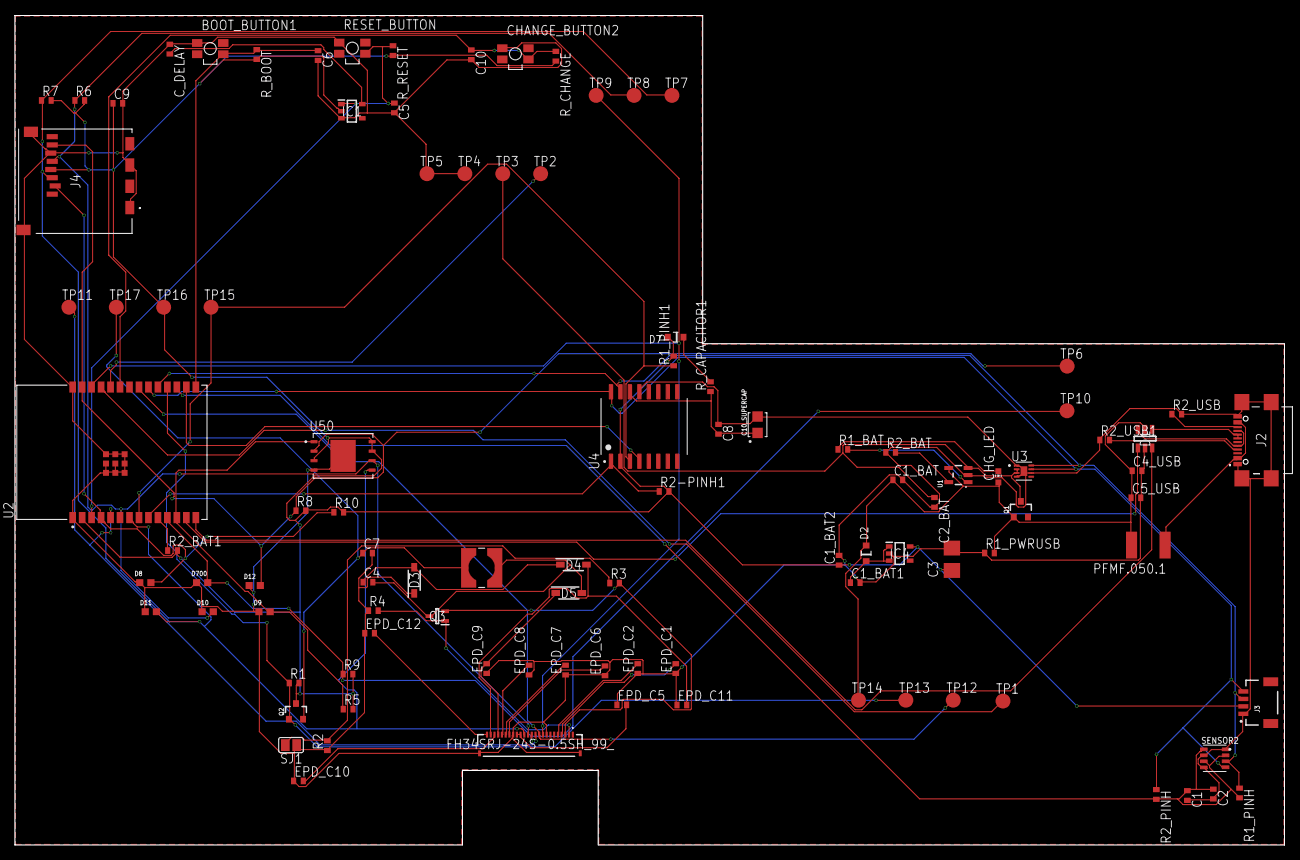
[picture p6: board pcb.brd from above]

Board: 2 copper layers, 170.2 x 111.2 mm, 103 parts (0 on the bottom side), 56 nets.

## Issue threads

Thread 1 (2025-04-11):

Planul de masă are găuri

cirstescuandrei, 2025-04-11:
**Problema:**

GND pour-ul este incomplet, și nu acoperă toată suprafața placii.

**Impact:**
- Impedanță crescută a planului de masă – afectează integritatea semnalelor.
- Bucle de masă (ground loops) – pot introduce zgomot și diferențe de potențial.
- Insule de cupru neconectate – pot cauza erori sau scurtcircuite.

**Soluție:**

Planurile de masa, atât pe Top cât și pe Bottom trebuie să fie uniforme.
Acest lucru se poate realiza prin selectarea GND pour-ului si bifarea opțiunii
'Orphans'.

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

Closed 2025-04-15.

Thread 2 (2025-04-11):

Grosime PCB

cirstescuandrei, 2025-04-11:
**Problema:**
Grosimea stratului dielectric al PCB-ului este mai mare decât este prevăzut,
anume 1.6mm în loc de 1mm.

**Impact:**

- Placa nu încape în carcasă.
- Conectorii nu se aliniază corect cu exteriorul carcasei.

**Soluție:**
De la tab-ul 'Preferences' -> 'Design Preferences' trebuie selectat
tab-ul de 'Layer Stack'. Dupa ce opțiunea 'Edit material properties' este
bifată, grosimea stratului dielectric poate fi modificată.

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

Closed 2025-04-15.

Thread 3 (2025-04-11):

Nume din Silkscreen peste trasee

cirstescuandrei, 2025-04-11:
**Problema:**

Numele unor componente din silkscreen se află peste trasee.

**Impact:**

- Dacă textul din silkscreen se află prea aproape de trasee, acestea pot
   interfera cu procesul de lipire a componentelor.
- Dacă textul se află pe trasee, poate face mai dificilă inspecția vizuală a
  traseelor și a componentelor.

**Soluție:**
Modificarea dimensiunii și poziției numelor din silkscreen astfel încât
să nu interfereze cu nicio componentă sau traseu, totodată păstrând
o dimensiune citibila a numelor. (min 0.5mm)

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

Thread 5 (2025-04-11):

Lipsa modele 3D pentru baterie și display

cirstescuandrei, 2025-04-11:
**Problemă:**
Modelele 3D pentru baterie și display lipsesc.

**Impact:**
- Fara modelele 3D și dimensiunile componentelor acestea
  nu pot fi produse și ar putea să nu încapă în carcasă alaturi
  de dispozitiv.

**Soluție:**
Modelerea 3D in Fusion a bateriei și a display-ului dupa
specificațiile date.

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

Closed 2025-04-15.

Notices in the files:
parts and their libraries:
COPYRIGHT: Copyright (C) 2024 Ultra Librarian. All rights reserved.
